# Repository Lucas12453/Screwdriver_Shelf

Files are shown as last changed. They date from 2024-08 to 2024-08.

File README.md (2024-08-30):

# Screwdriver Shelf
## Overview
Created to organize and centralize screwdrivers in the APIL workspace. It is made using 3D printed parts uniquely designed around each individual screwdriver. The shelf is able to comfortably hold 19 screwdrivers. 

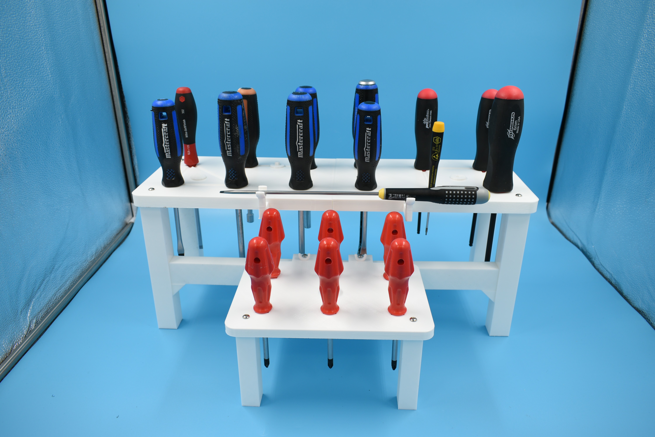
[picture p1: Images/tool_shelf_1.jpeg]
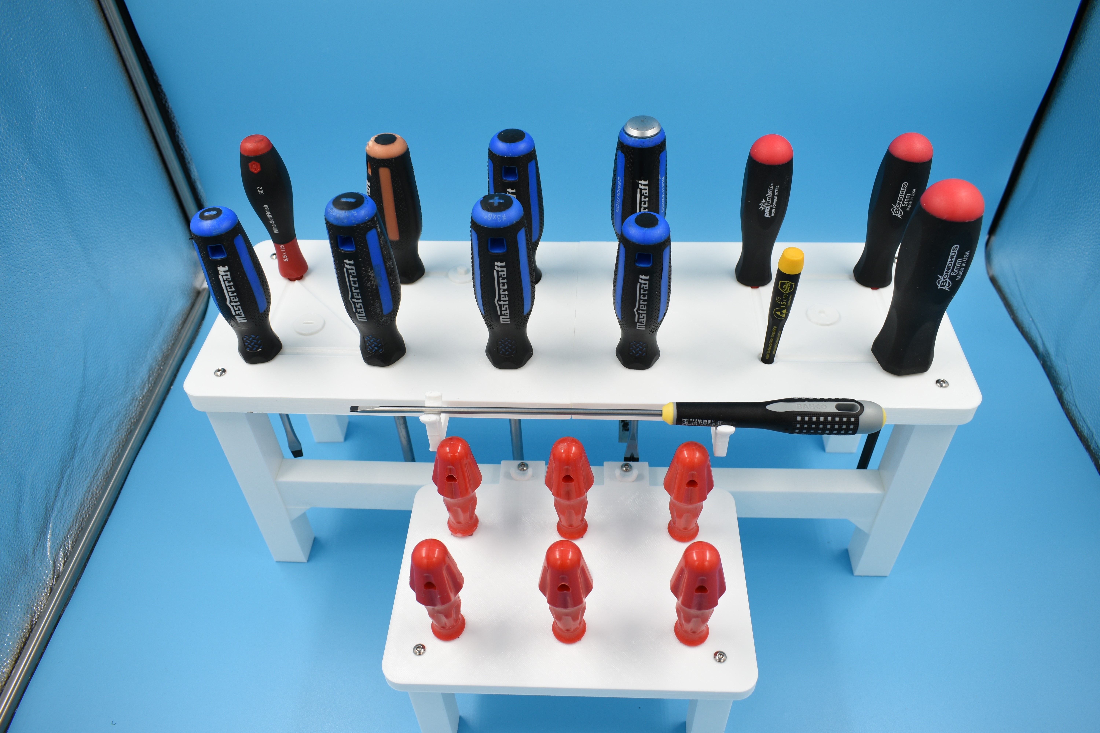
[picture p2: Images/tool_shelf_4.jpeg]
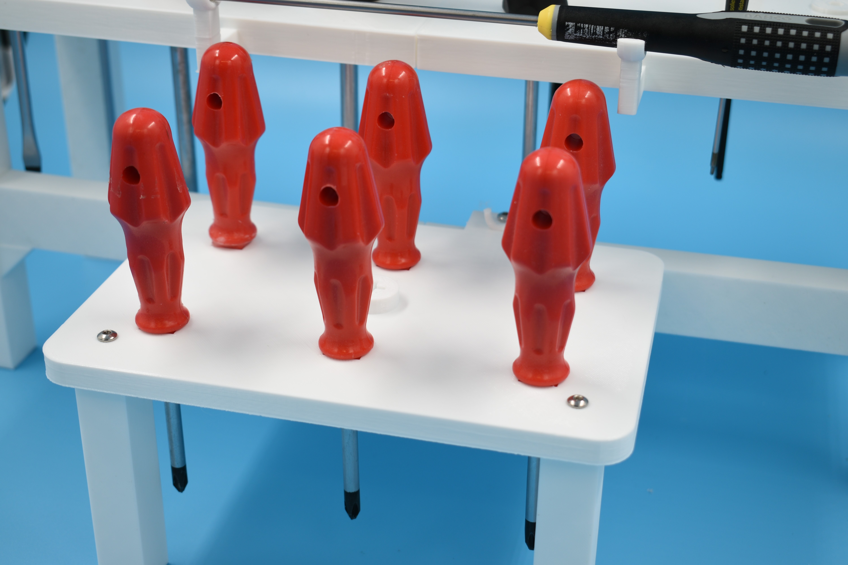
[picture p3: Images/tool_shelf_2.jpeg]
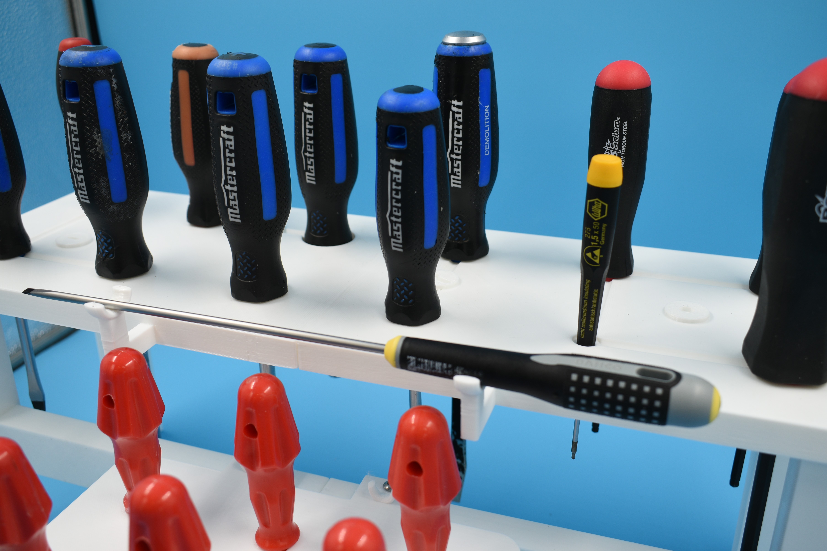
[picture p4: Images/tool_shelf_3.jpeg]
    

## Materials and Equipment  
- 4 x M4 14mm screws  
- 4 x M4 20mm screws  
- 4 x M4 25mm screws  
- 2 x M4 40mm screws

### Printing:  
PLA (polylactic acid) filament  
3D printer (a Prusa i3 MK3 printer was used here)

## Parts  
M- main  
S- secondary

C- connector  
L- leg  
P- panel

D- depressed  
E- extruding  

- 1 x MC  
- 1 x SCE  
- 1 x SCD  
- 2 x MLE  
- 2 x MLD  
- 2 x SL  
- 1 x MPE  
- 1 x MPD  
- 1 x SP

## Assembly

1. Using the M4 25mm screws, attach the 4 long legs (MLE; MLD) to the flat bottom of the 2 large panels (MPE; MPD), 1 leg on each rounded corner. Be sure to position the 2 legs with the extruding triangular supports (MLE) towards each other across the long side of the shelf. Depending on preference, the arms on the panels can be either in the front, or the back of the shelf. The side that the supports are on will be the front of the shelf.  
2. Match the 4 holes on the planar, rectangular connector (MC) with the holes on the bottom of the 2 large panels (MPE; MPD), and attach them with the M4 14mm screws.   
3. Fit the dovetail design of the 2 slim connectors (SCE; SCD) together. With the 2 closely located holes facing up towards the large panels (MPE; MPD), place it so it sits, bridging the gap between the 2 triangular supports. Matching its holes with the holes on the legs (MLE), attach them using the M4 40mm screws.  
4. Take the small panel (SP) and with the phillips head emblem facing up, position its extruding ends with holes on the slim connector (SCE; SCD). Attach it using 2 M4 20mm screws.   
5. Place the 2 small legs (SL) in line with the holes on the 2 corners of the small panel (SP), and connect them using 2 M4 20mm screws.

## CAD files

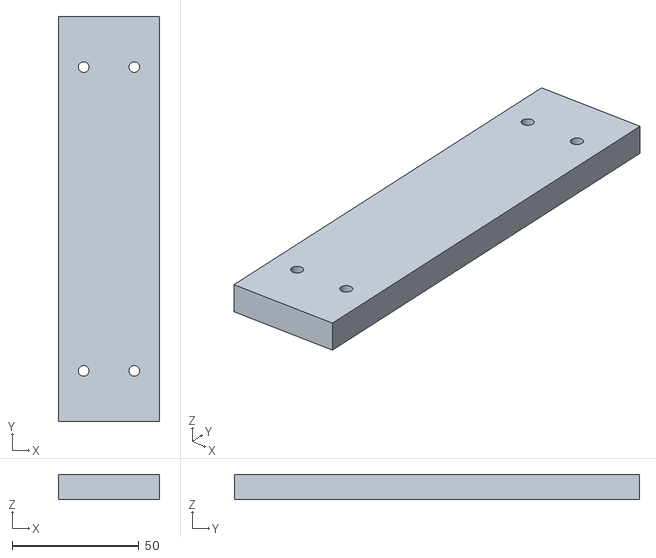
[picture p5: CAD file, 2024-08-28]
STL/MC.stl
40.0 x 160.0 x 10.0

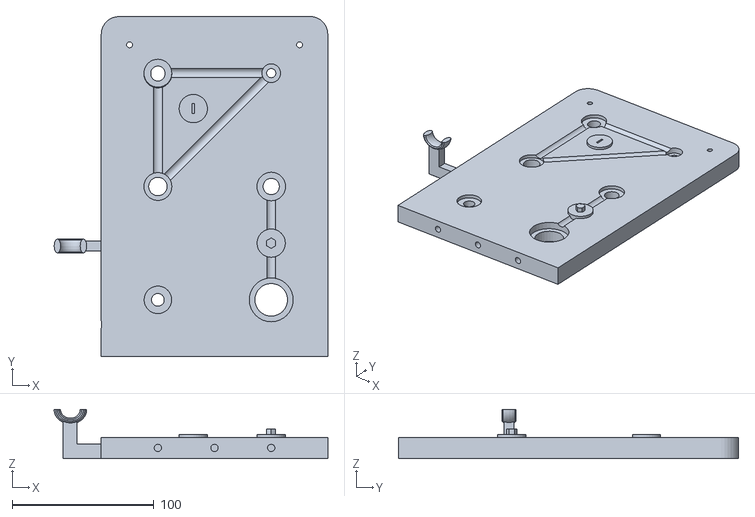
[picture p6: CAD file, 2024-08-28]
STL/MPE.stl
193.2 x 240.0 x 34.6

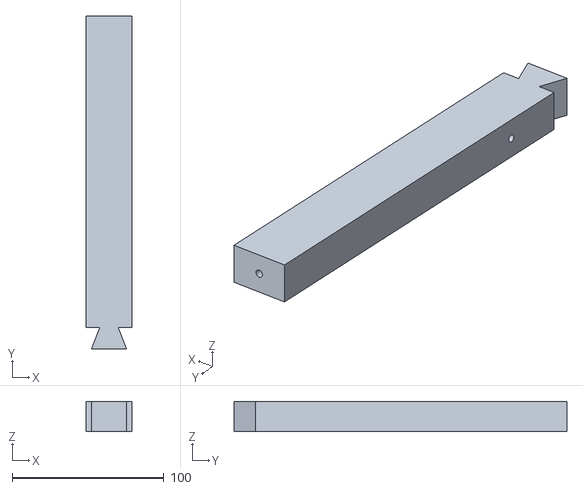
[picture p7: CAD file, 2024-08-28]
STL/SCE.stl
30.0 x 219.2 x 20.0

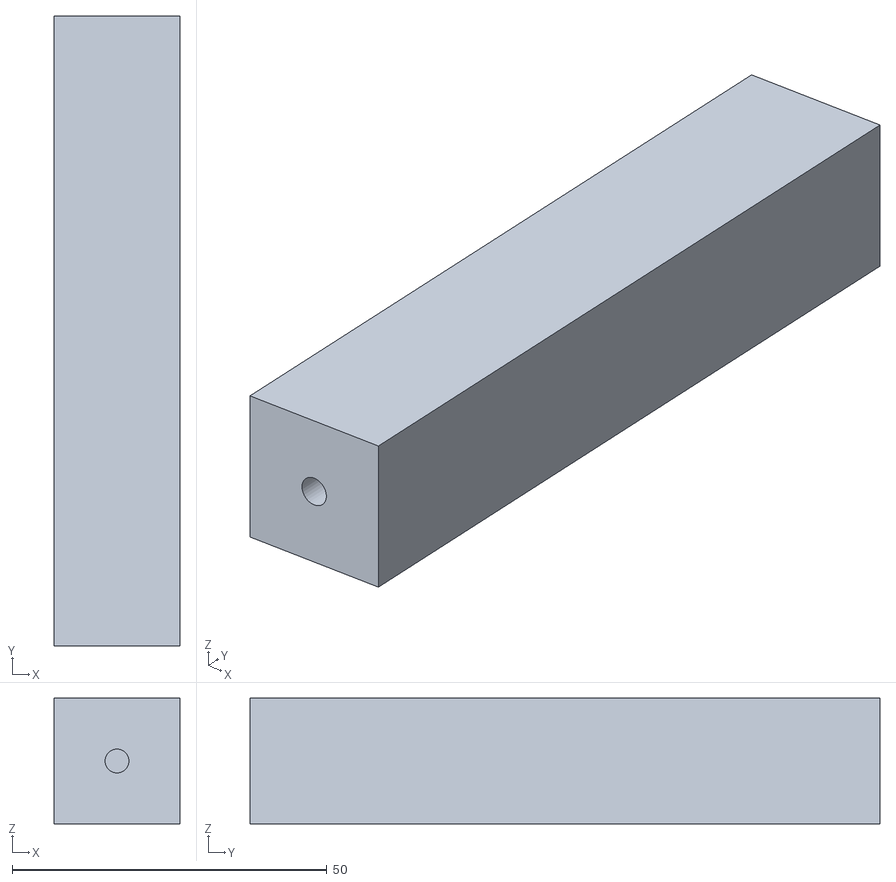
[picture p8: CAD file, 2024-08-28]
STL/SL.stl
20.0 x 100.0 x 20.0

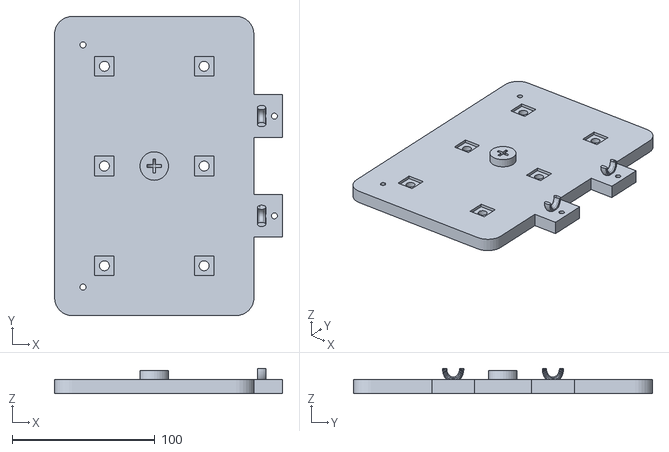
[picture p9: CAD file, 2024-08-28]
STL/SP.stl
160.0 x 210.0 x 17.8

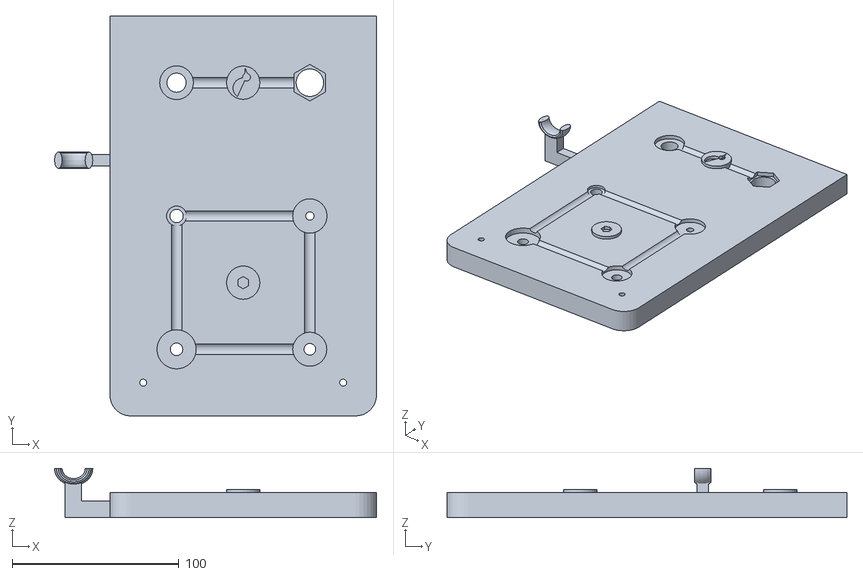
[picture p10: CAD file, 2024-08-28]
STL/MPD.stl
193.2 x 240.0 x 29.6

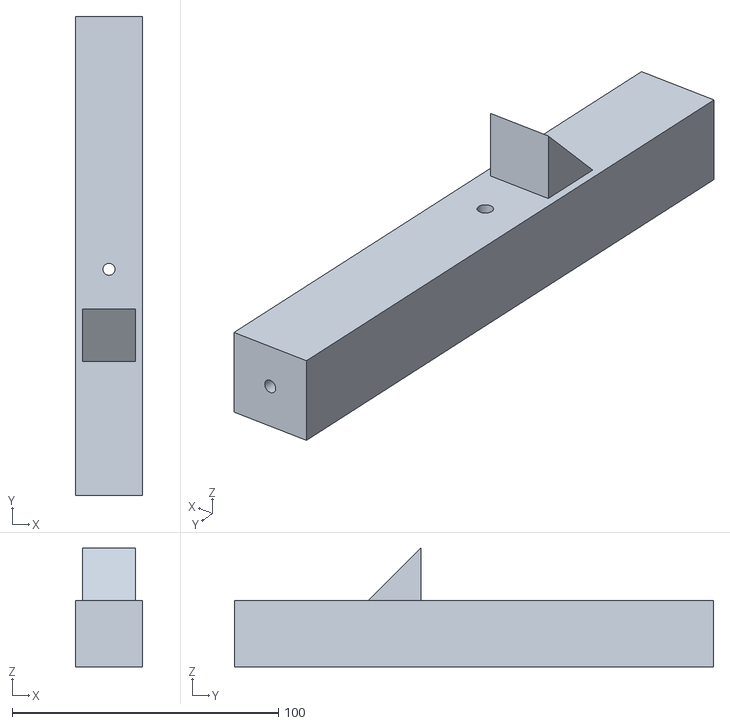
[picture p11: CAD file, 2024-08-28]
STL/MLE.stl
25.0 x 180.0 x 44.7

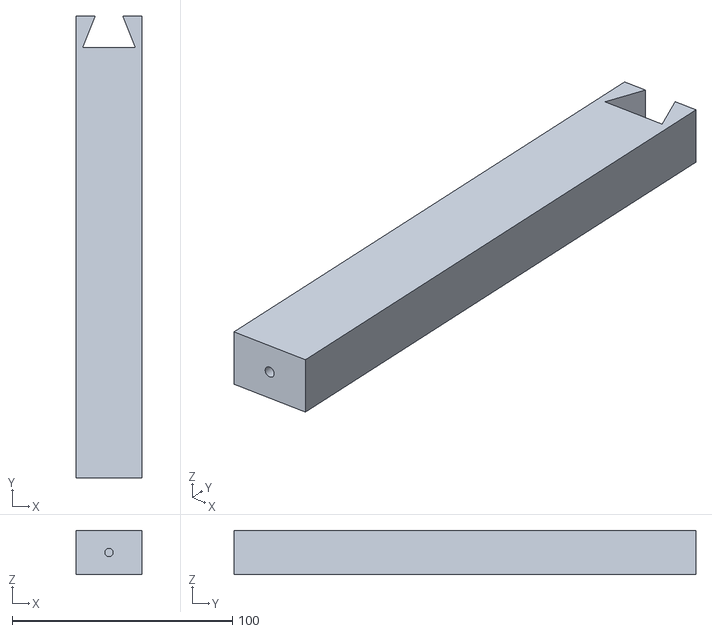
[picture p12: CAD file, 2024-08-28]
STL/SCD.stl
30.0 x 210.0 x 20.0

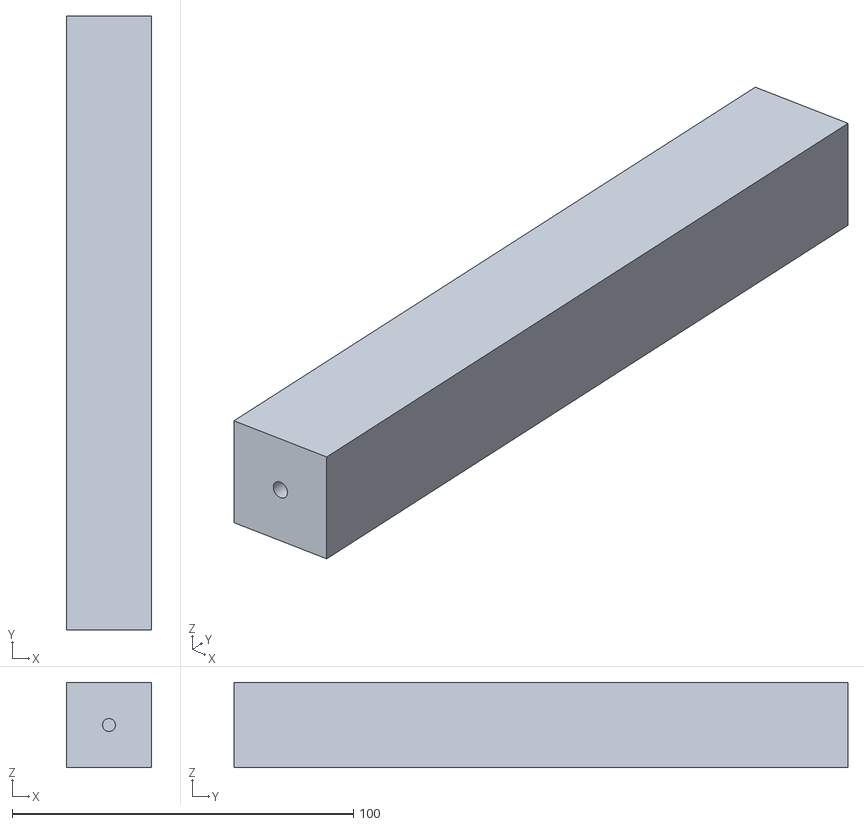
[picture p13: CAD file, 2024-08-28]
STL/MLD.stl
25.0 x 180.0 x 25.0
